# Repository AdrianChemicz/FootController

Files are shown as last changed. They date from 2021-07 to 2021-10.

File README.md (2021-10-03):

# FootController

## 1.Introduction

Main idea behind Footcontroller project was create device which allow user send keyboard event via foot move. This type of press key can be used in game in some circumstances it can be convienient more then standard press key on typical keyboard. When hold one button is required and press other parallel is required then footcontroller is good solution.

Device overview

## 2.Mechanical description

Device is connected to pc via USB cable. On device side is used USB mini connector.<br />
Device detect foot move via laser sensor and appropriate place for sensor was selected. <br />
In housing was prepared holes for power led, USB serial led, laser sensor and for USB connector. On below schematic was presented all part of device with descriptions.<br />

Device view

Index | Part of device description
------------ | -------------
1 | Laser sensor
2 | Power ON green LED
3 | Debug port connector
4 | USB serial port LED indicator
5 | Mini USB B port

On below schematic was presented all parts used in device.

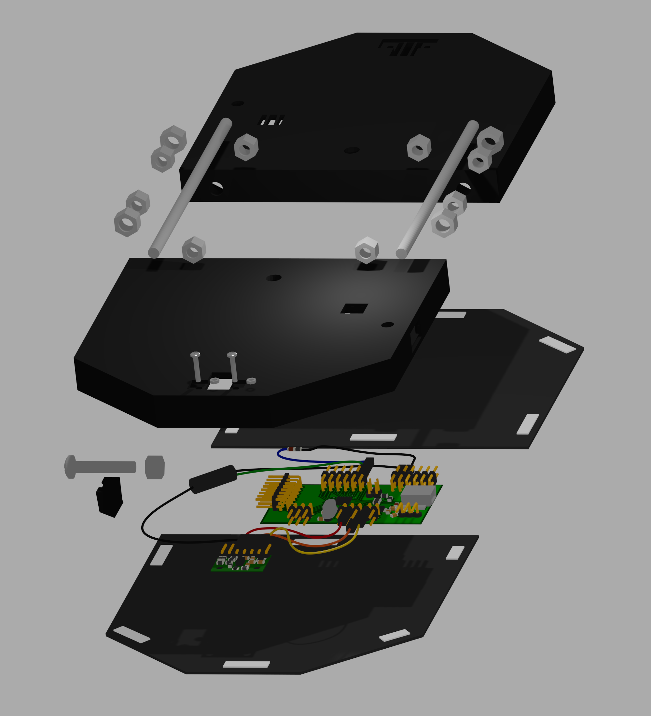
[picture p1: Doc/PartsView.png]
Device view


## 3.System usage

Device after connect to system is visible as composite device it mean that in single device can be present more than one function. In footcontroller was implemented HID keyboard and CDC(USB serial interface). HID keyboard functionality send event when laser event will be detected. Configuration which key must be presed, mode of pressing and threshold can be configure via USB serial interface.<br /><br />
USB serial interface driver of this device was added to this project and is available in folder "Driver".
When device is connected to PC and serial port will be open then key event will be suppres on 30s. On serial port device can display manual with supported command description. To display manual please send AT_HELP or HELP. Below was added help manual which will be send by device:
>Foot controller serial port is used to configure device and diagnose that device work properly<br />
>Configuration is performed using AT command. When serial port will be opened send button event will be blocked on 30s from serial port opening.<br />
>Device support below AT command<br />
>AT_SENSOR_ - command used to configure mode of laser sensor to decide how and when press keyboard button. Configuration of button is also possible.<br />
>Command expect parameters in order the same as order of described parameters.<br />
>1\. Sensor number - parameter describe about to which sensor number will be assigned key code, mode and threshold value. Value is stored in decimal format.<br />
>Format of parameter:<br />
>\<Sensor number\><br />
>2. Mode of pressing button - parameter decide how button will be pressed. Two options is possible:<br />
>PRESS - when event from laser sensor occur button will be pressed only one time even if event will be all time present.<br />
>HOLD - when event from laser sensor occur button will be pressed and will be present to moment when laser sensor detect that event disappear.<br />
>Format of parameter:<br />
>MODE_PRESS<br />
>3. Key code - parameter decide which key will be pressed when event occur. Value is stored in decimal format.<br />
>Format of parameter:<br />
>KEYCODE_6<br />
>Few key code example:<br />
>17 - N<br />
>6 - C<br />
>20 - Q<br />
>4. Threshold - parameter describe distance how far foot must be move from laser sensor to occur event. Distance is stored in milimiters and in decimal formats.<br />
>Format of parameter:<br />
>THRESHOLD_20<br />
>Example complete AT command formats:<br />
>AT_SENSOR_0_MODE_PRESS_KEYCODE_6_THRESHOLD_20<br />
>AT_SENSOR_0_MODE_HOLD_KEYCODE_17_THRESHOLD_20<br />
>AT_GET_RANGE_COUNT_ - command used to check range measured by laser sensor. Data displayed by this command is as raw milimeter without any preprocesing.<br />
>Command need only one parameter which mean number of get range samples. Number of samples must be set in decimal format.<br />
>Example complete AT command formats:<br />
>AT_GET_RANGE_COUNT_99<br />
>AT_STATUS - command used to verify that device work correctly.<br />
>Command return information about device current status, number of errors last errors code.<br />
>Status and error code equal 0 mean no errors<br />
>Example complete AT command format:<br />
>AT_STATUS<br />
>AT_EVENT_SUSPEND - command used to block button event send by device. This command is active to moment when serial port will be closed.<br />
>Example complete AT command format:<br />
>AT_EVENT_SUSPEND<br />
>AT_EVENT_PARAMETERS - command used to display parameters used by sensors. Command will display important information like:<br />
>key mode, key code, threshold need for cause key event, offset value(value used to compare with threshold is - offset value + raw laser sensor range)<br />

## 4.Electrical schematic

In device was used PCB with microcontroller LPC11U24. This PCB was created in KiCad application and all files created during board preparation was added to PCB project folder.
Below was added connection between main microcontroller and other part of system. In device was used pololu module with ST VL53L0X laser sensor(dev code of board: irs11a). Laser sensor is reset via BC817-25W NPN transistor.

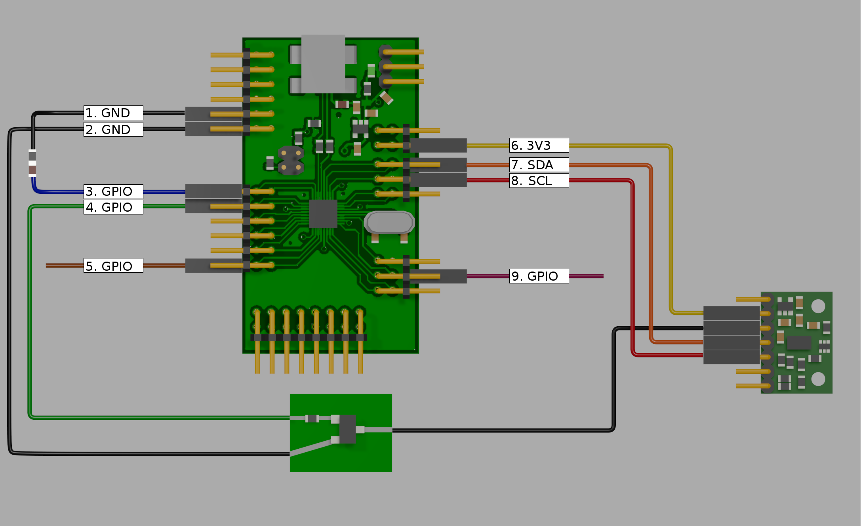
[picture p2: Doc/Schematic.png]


Index | Pin function | Pin usage
------------ | ------------ | -------------
1 | GND | Ground for LED
2 | GND | Ground connected to BC817-25W transistor emiter pin
3 | GPIO | Output port use to control CDC LED indicator
4 | GPIO | Output port use to control BC817-25W transistor base pin
5 | GPIO | Output port use to debug durring development process
6 | 3V3 | 3.3V power supply for laser sensor
7 | SDA | I2C data pin use to comunication with laser sensor
8 | SCL | I2C clock pin use to comunication with laser sensor
9 | GPIO | Input port use to block send key event from laser. Connect to ground to block event.

## 5.Housing of device

Housing of device was prepared in Blender application. Complete housing consist of two element main element and electronic board holder. To mount complete device is require put three or two nuts for screw and threaded rod to nut holes in main element. 

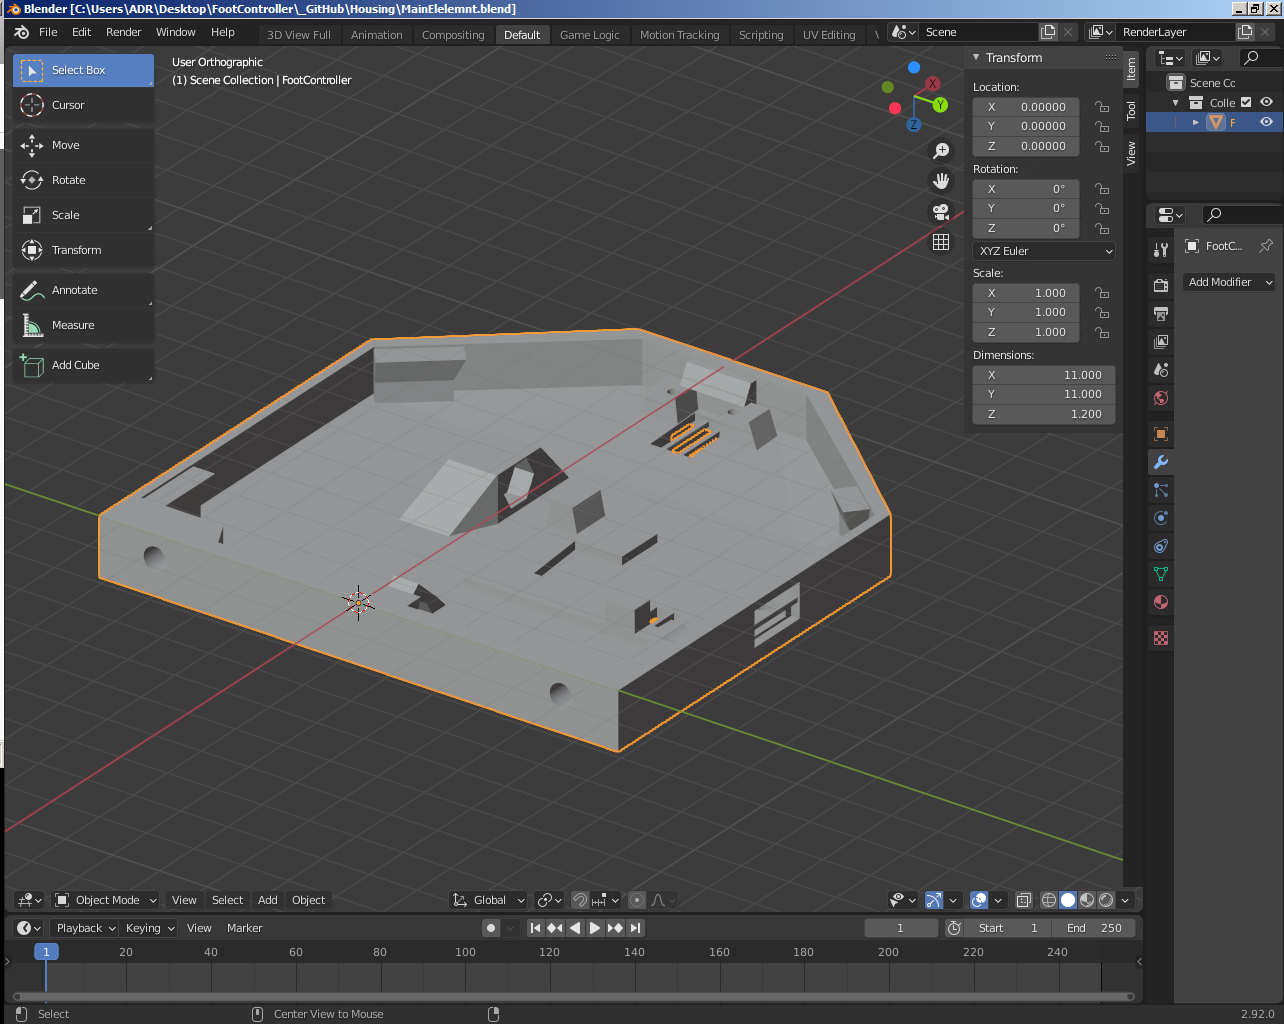
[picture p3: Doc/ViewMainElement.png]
Main element in blender


In Housing project folder was added blender files with single element and all steps(before using boolean modifier) necessary to create final element.

## 6.Code design

Footcontroller source code firmware was divided into few modules which was divided according to purpose. In below table was added all modules in project:

Module name | Module description
------------ | ------------
Descriptors.h | Contain USB things like structures and information which will be visible on PC after device connection
EEPROM_Driver.h | Provide function to read and write functions to store information about sensor activation parameters
FootController.h | Main module with main function. Module handle USB communication like serial and HID interfaces.
GPIO_Driver.h | Provide API for GPIO microcontrollers ports
HW_Driver.h | Module responsible for clock microcontroller clock settings and communication with laser sensor.
I2C_Driver.h | Provide API for I2C microcontroller interface
iap.h | Provide API to manage EEPROM memory and flash.
StringGenerateParseModule.h | Provide API to parse or generate strings. Functions in module are used by USB serial communication.

FootController.h module between other modules share FootControllerStructure which is visible as global variable. Many functions from other modules access to field in this structure directly.

To build firmware also was used ST VL53L0X API library to handle VL53L0X full sensor i2c comunication. ST library provide all necessary API to comunicate with sensor without manual call I2C API. API is available on below location:<br />
https://www.st.com/en/embedded-software/stsw-img005.html <br />
Project also use two other library which not exist in project directory but to correct compile file must be added outside. Those library are lpc_chip_11uxx_lib and nxp_lpcxpresso_11u14_usblib_device. 

Project to compile without errors require from user additional steps. Assign VID and PID number in Descriptors.c file because author of project isn't usb.org member or didn't buy VID number. The same thing must be performed with FootControllerSerialDriver.inf driver file in Driver project folder. Below was added screenshot both file with marked code lines when changes must be performed. In both file VID and PID must be the same.

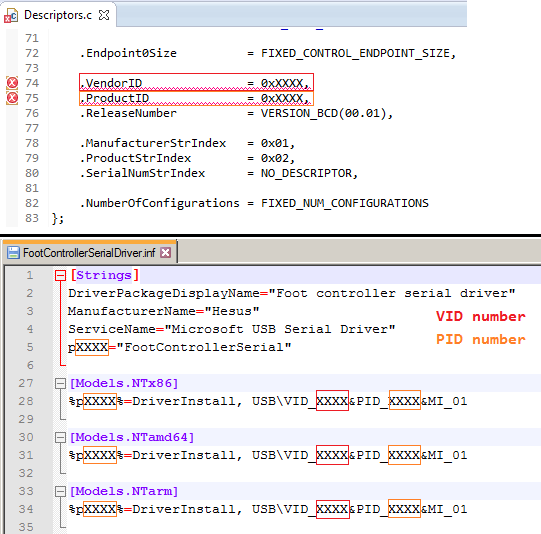
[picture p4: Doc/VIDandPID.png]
VID and PID


## 7.Execution sequence diagram

On below schematic was presented how application running on footcontroller to provide overal information before deeper code analisis.

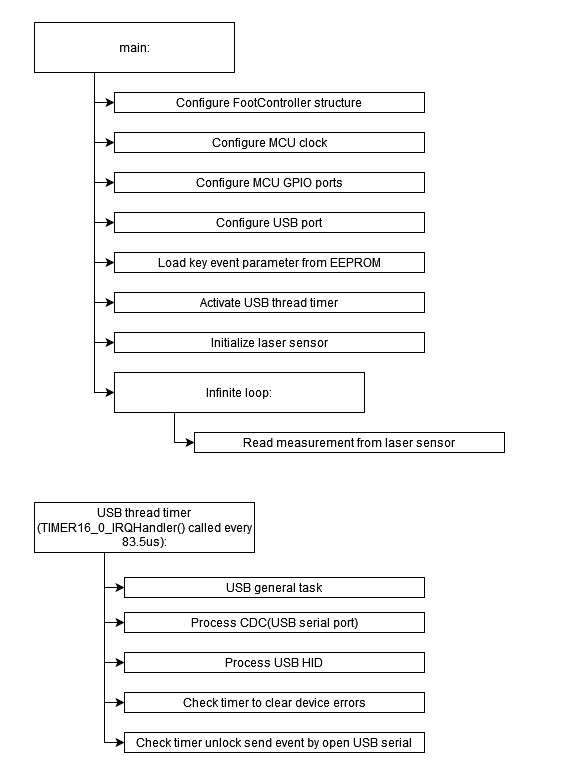
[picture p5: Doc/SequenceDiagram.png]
Sequence diagram

  
In main function after initialization is executed in infinite loop laser sensor handling. USB process is performed in TIMER16_0_IRQHandler timer interrupt which is call every 83.5 us.

## 8.Known issues

-Very often device send null signs in string to PC on serial port. Issue can be cause by incorrect use NXP USB library.

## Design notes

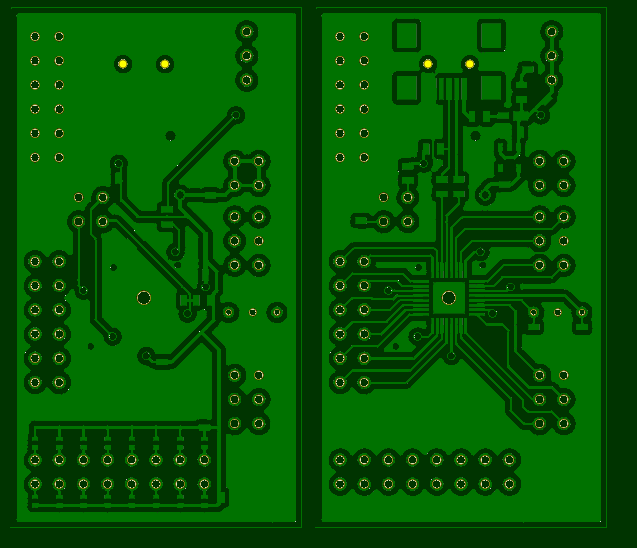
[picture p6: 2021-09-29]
Doc/Blender/PCB_Blender3.png

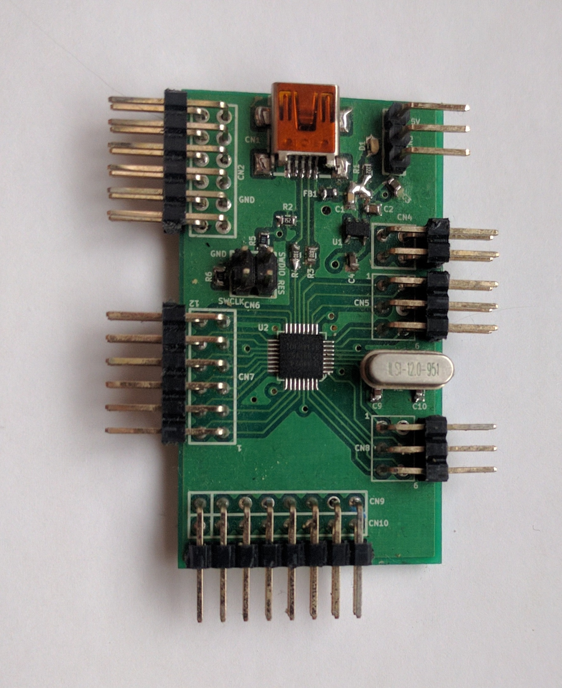
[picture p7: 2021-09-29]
PCB/PCB_UpLayer.jpg

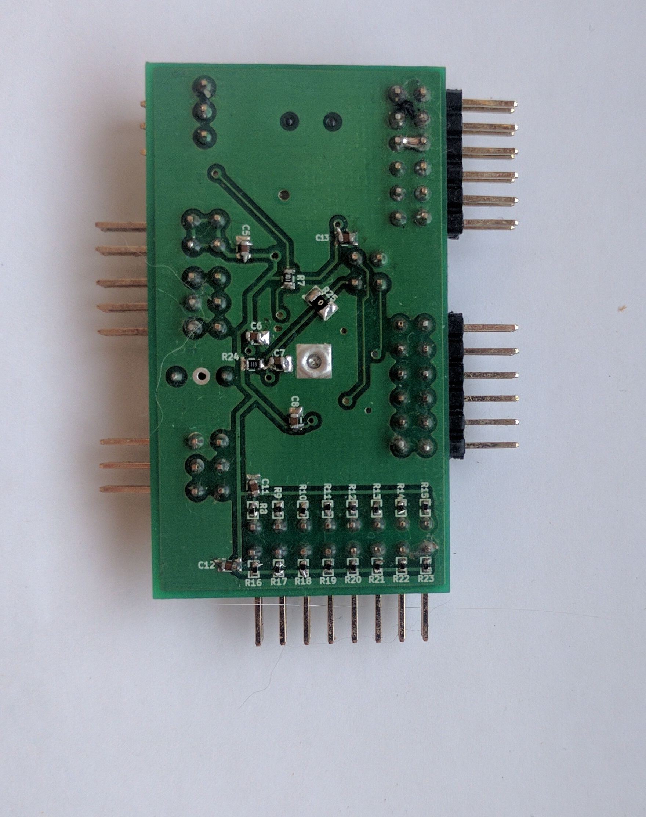
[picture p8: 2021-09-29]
PCB/PCB_DownLayer.jpg

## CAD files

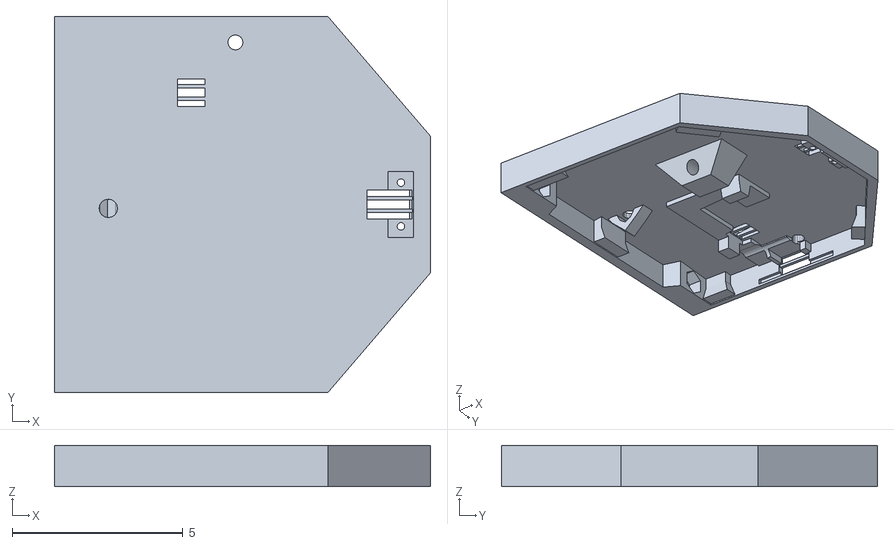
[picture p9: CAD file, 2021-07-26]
Housing/MainElelemnt.stl
11.0 x 11.0 x 1.20

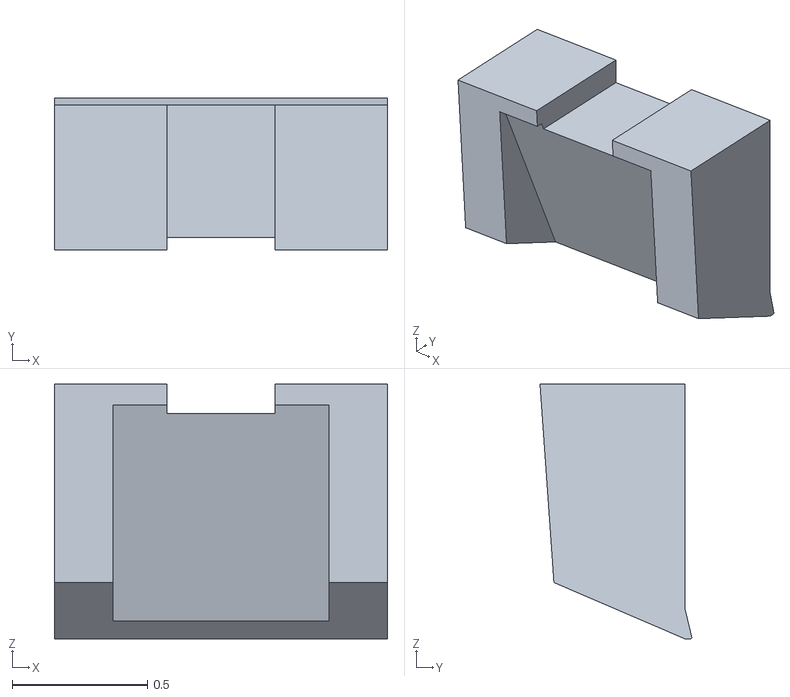
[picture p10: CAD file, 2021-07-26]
Housing/BoardLocker.stl
1.23 x 0.562 x 0.942

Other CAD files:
Doc/Blender/AllElementsFinal.blend
Doc/Blender/PartsView.blend
Doc/Blender/schematic.blend
Housing/BoardLocker.blend
Housing/BoardLocker_AllSteps.blend
Housing/MainElelemnt.blend
Housing/MainElelemnt_AllSteps.blend

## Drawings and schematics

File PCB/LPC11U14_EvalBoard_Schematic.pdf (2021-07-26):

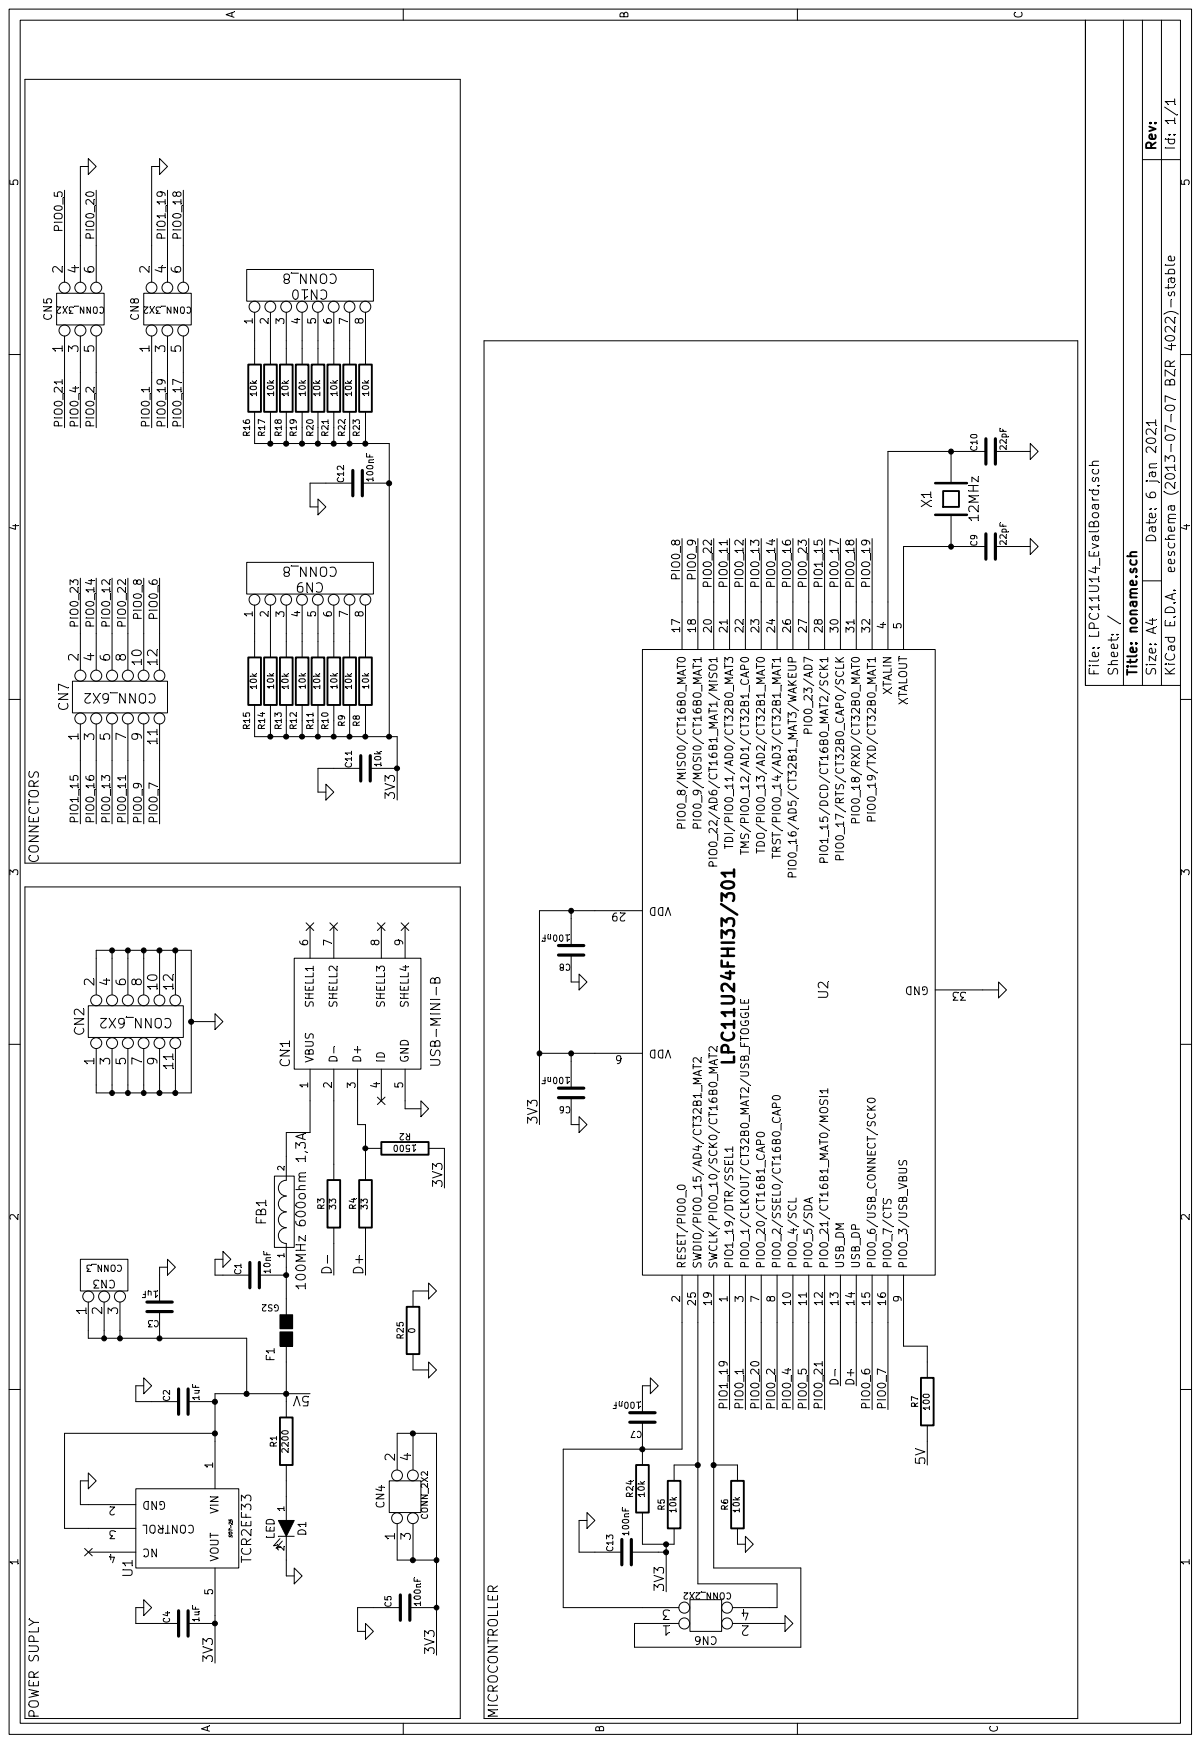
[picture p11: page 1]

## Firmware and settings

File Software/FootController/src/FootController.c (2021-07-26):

/*
 * Copyright (c) 2021, Adrian Chemicz
 * All rights reserved.
 *
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
 * THIS SOFTWARE IS PROVIDED BY THE COPYRIGHT HOLDERS AND CONTRIBUTORS "AS IS" AND
 * ANY EXPRESS OR IMPLIED WARRANTIES, INCLUDING, BUT NOT LIMITED TO, THE IMPLIED
 * WARRANTIES OF MERCHANTABILITY AND FITNESS FOR A PARTICULAR PURPOSE ARE
 * DISCLAIMED. IN NO EVENT SHALL COPYRIGHT HOLDER BE LIABLE FOR ANY
 * DIRECT, INDIRECT, INCIDENTAL, SPECIAL, EXEMPLARY, OR CONSEQUENTIAL DAMAGES
 * (INCLUDING, BUT NOT LIMITED TO, PROCUREMENT OF SUBSTITUTE GOODS OR SERVICES;
 * LOSS OF USE, DATA, OR PROFITS; OR BUSINESS INTERRUPTION) HOWEVER CAUSED AND
 * ON ANY THEORY OF LIABILITY, WHETHER IN CONTRACT, STRICT LIABILITY, OR TORT
 * (INCLUDING NEGLIGENCE OR OTHERWISE) ARISING IN ANY WAY OUT OF THE USE OF THIS
 * SOFTWARE, EVEN IF ADVISED OF THE POSSIBILITY OF SUCH DAMAGE.
 */

#include "USB.h"
#include <stdbool.h>
#include <string.h>
#include "Descriptors.h"
#include "chip.h"
#include "GPIO_Driver.h"
#include "vl53l0x_api.h"
#include "vl53l0x_platform.h"

#include "FootController.h"
#include "EEPROM_Driver.h"
#include "HW_Driver.h"
#include "StringGenerateParseModule.h"

/*****************************************************************************
*	String used by virtual serial USB in at command as responses
*****************************************************************************/
const char *helpString = "\r\nFoot controller serial port is used to configure device and diagnose that device work properly\r\n\
Configuration is performed using AT command. When serial port will be opened send button event will be blocked on 30s from serial port opening.\r\n\
Device support below AT command.\r\n\r\n\
AT_SENSOR_ - command used to configure mode of laser sensor to decide how and when press keyboard button. Configuration of button is also possible.\r\n\
Command expect parameters in order the same as order of described parameters.\r\n\r\n\
1. Sensor number - parameter describe about to which sensor number will be assigned key code, mode and threshold value. Value is stored in decimal format.\r\n\r\n\
Format of parameter:\r\n\
<Sensor number>\r\n\r\n\
2. Mode of pressing button - parameter decide how button will be pressed. Two options is possible:\r\n\
PRESS - when event from laser sensor occur button will be pressed only one time even if event will be all time present.\r\n\
HOLD - when event from laser sensor occur button will be pressed and will be present to moment when laser sensor detect that event disappear.\r\n\
Format of parameter:\r\n\
MODE_PRESS\r\n\r\n\
3. Key code - parameter decide which key will be pressed when event occur. Value is stored in decimal format.\r\n\
Format of parameter:\r\n\
KEYCODE_6\r\n\r\n\
Few key code example:\r\n\
17 - N\r\n\
6 - C\r\n\
20 - Q\r\n\r\n\
4. Threshold - parameter describe distance how far foot must be move from laser sensor to occur event. Distance is stored in milimiters and in decimal formats.\r\n\r\n\
Format of parameter:\r\n\
THRESHOLD_20\r\n\r\n\
Example complete AT command formats:\r\n\
AT_SENSOR_0_MODE_PRESS_KEYCODE_6_THRESHOLD_20\r\n\
AT_SENSOR_0_MODE_HOLD_KEYCODE_17_THRESHOLD_20\r\n\r\n\
AT_GET_RANGE_COUNT_ - command used to check range measured by laser sensor. Data displayed by this command is as raw milimeter without any preprocesing.\r\n\
Command need only one parameter which mean number of get range samples. Number of samples must be set in decimal format.\r\n\r\n\
Example complete AT command formats:\r\n\
AT_GET_RANGE_COUNT_99\r\n\r\n\
AT_STATUS - command used to verify that device work correctly.\r\n\
Command return information about device current status, number of errors last errors code.\r\n\
Status and error code equal 0 mean no errors\r\n\r\n\
Example complete AT command format:\r\n\
AT_STATUS\r\n\r\n\
AT_EVENT_SUSPEND - command used to block button event send by device. This command is active to moment when serial port will be closed.\r\n\
Example complete AT command format:\r\n\
AT_EVENT_SUSPEND\r\n\r\n\
AT_EVENT_PARAMETERS - command used to display parameters used by sensors. Command will display important information like:\r\n\
key mode, key code, threshold need for cause key event, offset value(value used to compare with threshold is - offset value + raw laser sensor range)\r\n";

const char *invalidParametersString = " - invalid parameters\r\n";
const char *correctParametersString = " - correct parameters\r\n";
const char *invalidCommandString = " - invalid command\r\n";
const char *errorProgramExecutionString = " - error in code execution\r\n";

/*****************************************************************************
*	Data for virtual serial port to control method of responses for at
*	commmand.
*****************************************************************************/
uint8_t receiveTransmitCdcBuffer[CDC_TXRX_EPSIZE];
uint8_t stringCdcTransmitBuffer[CDC_TXRX_EPSIZE*4];
CDC_MessageStructureType CDC_MessageStructure;

//global structure available in many modules. It is provided by FootController.h file
FootControllerStructureType FootControllerStructure;

static uint8_t PrevKeyboardHIDReportBuffer[sizeof(USB_KeyboardReport_Data_t)];

/*****************************************************************************
*	Structures used by NXP USB library. Structure is pass as reference for
*	NXP USB library functions. In below code was presenets structure for
*	HID and CDC interfaces.
*****************************************************************************/
//this structure is availiable externaly - is provided by FootController.h file
USB_ClassInfo_HID_Device_t Keyboard_HID_Interface = {
	.Config = {
		.InterfaceNumber              = 0,

		.ReportINEndpointNumber       = KEYBOARD_EPNUM,
		.ReportINEndpointSize         = KEYBOARD_EPSIZE,
		.ReportINEndpointDoubleBank   = false,

		.PrevReportINBuffer           = PrevKeyboardHIDReportBuffer,
		.PrevReportINBufferSize       = sizeof(PrevKeyboardHIDReportBuffer),
		.PortNumber             = 0,
	},
};

USB_ClassInfo_CDC_Device_t VirtualSerial_CDC_Interface = {
	.Config = {
		.ControlInterfaceNumber         = 1,

		.DataINEndpointNumber           = CDC_TX_EPNUM,
		.DataINEndpointSize             = CDC_TXRX_EPSIZE,
		.DataINEndpointDoubleBank       = false,

		.DataOUTEndpointNumber          = CDC_RX_EPNUM,
		.DataOUTEndpointSize            = CDC_TXRX_EPSIZE,
		.DataOUTEndpointDoubleBank      = false,

		.NotificationEndpointNumber     = CDC_NOTIFICATION_EPNUM,
		.NotificationEndpointSize       = CDC_NOTIFICATION_EPSIZE,
		.NotificationEndpointDoubleBank = false,
		.PortNumber             = 0,
	},
};

/*****************************************************************************************
* ProcessCdc() - main task of this function is process virtual serial USB request send by
* PC. In this part of code request is checked that it is handle by device and parameters
* added to request is correct. Request send to device use at command format. After
* validation request function also start appropriate process of command. Function set field
* in FootControllerStructure and later those data is used in other functions to generate
* data for response or decide how device will work. State how execution should be performed
* is stored in structure which is pass to function via structure pointer set as parameter.
*
* Parameters:
* @CDC_MessageStructurePointer: pointer to structure which contain parameters with state
* of processed command
*****************************************************************************************/
static void ProcessCdc(CDC_MessageStructureType *CDC_MessageStructurePointer)
{
	uint16_t recvByteCountTmp = CDC_Device_BytesReceived(&VirtualSerial_CDC_Interface);

	if (recvByteCountTmp > 0)
	{
		FootControllerStructure.processedCommand = (uint8_t)UNKNOWN_COMMAND;
		FootControllerStructure.correctCommandParametersFlag = true;

		CDC_MessageStructurePointer->duringSendTransactionFlag = false;
		CDC_MessageStructurePointer->transactionSendWaitCounter = NUMBER_OF_SEND_WAIT_CYCLE;

		memset(receiveTransmitCdcBuffer , 0, CDC_TXRX_EPSIZE);
		for (int i = 0; i < recvByteCountTmp; i++)
		{
			receiveTransmitCdcBuffer[i] = CDC_Device_ReceiveByte(&VirtualSerial_CDC_Interface);
		}

		//check that payload contain one of below strings on beginning
		//verify HELP COMMAND
		{
			if ((strstr(receiveTransmitCdcBuffer, "AT_HELP") != NULL && strstr(receiveTransmitCdcBuffer, "AT_HELP") == receiveTransmitCdcBuffer && receiveTransmitCdcBuffer[sizeof("AT_HELP")] == 0)
				|| (strstr(receiveTransmitCdcBuffer, "HELP") != NULL && strstr(receiveTransmitCdcBuffer, "HELP") == receiveTransmitCdcBuffer && receiveTransmitCdcBuffer[sizeof("HELP")] == 0))
			{
				FootControllerStructure.processedCommand = (uint8_t)HELP_COMAMND;
			}
		}
		//verify AT_STATUS
		{
			if (strstr(receiveTransmitCdcBuffer, "AT_STATUS") != NULL && strstr(receiveTransmitCdcBuffer, "AT_STATUS") == receiveTransmitCdcBuffer && receiveTransmitCdcBuffer[sizeof("AT_STATUS")] == 0)
			{
				FootControllerStructure.processedCommand = (uint8_t)STATUS_COMAMND;
			}
		}
		//verify AT_SENSOR_
		{
			if (strstr(receiveTransmitCdcBuffer, "AT_SENSOR_") != NULL && strstr(receiveTransmitCdcBuffer, "AT_SENSOR_") == receiveTransmitCdcBuffer)
			{
				SensorActivationParametersType sensorActivationParametersTmp;
				uint8_t sensorNumber;
				uint8_t copyOfCheckedBuffer[CDC_TXRX_EPSIZE];

				memcpy(copyOfCheckedBuffer, receiveTransmitCdcBuffer, CDC_TXRX_EPSIZE);

				FootControllerStructure.processedCommand = (uint8_t)CONFIGURE_SENSOR_COMAMND;

				if (parseConfigureSensorCommandParameters(strtok(&copyOfCheckedBuffer[sizeof("AT_SENSOR_") - 1], "_"), &sensorActivationParametersTmp, &sensorNumber))
				{
					if (sensorNumber > (MAX_SUPPORTED_SENSOR - 1))
					{
						FootControllerStructure.correctCommandParametersFlag = false;
					}
					else
					{
						FootControllerStructure.sensorActivationParametersTable[sensorNumber] = sensorActivationParametersTmp;

						SensorActivationParametersEepromStoreType sensorActivationParametersEepromContent;

						sensorActivationParametersEepromContent.sensorActivationParameters = sensorActivationParametersTmp;

						WriteSensorDataToEeprom(&sensorActivationParametersEepromContent, sensorNumber);
					}
				}
				else
				{
					FootControllerStructure.correctCommandParametersFlag = false;
				}
			}/* if (strstr(receiveTransmitCdcBuffer, "AT_SENSOR_") != NULL && strstr(receiveTransmitCdcBuffer, "AT_SENSOR_") == receiveTransmitCdcBuffer) */
		}
		//verify AT_GET_RANGE_COUNT_
		{
			if (strstr(receiveTransmitCdcBuffer, "AT_GET_RANGE_COUNT_") != NULL
				&& strstr(receiveTransmitCdcBuffer, "AT_GET_RANGE_COUNT_") == receiveTransmitCdcBuffer)
			{
				uint16_t numberOfRangeMeasurementTmp = 0;

				FootControllerStructure.processedCommand = (uint8_t)GET_RANGE_COMAMND;

				//verfy parameter
				numberOfRangeMeasurementTmp = atoi(&receiveTransmitCdcBuffer[sizeof("AT_GET_RANGE_COUNT_") - 1]);

				if(!onlyDigitsExistInString(&receiveTransmitCdcBuffer[sizeof("AT_GET_RANGE_COUNT_") - 1]))
				{
					FootControllerStructure.correctCommandParametersFlag = false;
				}

				if(numberOfRangeMeasurementTmp == 0 || numberOfRangeMeasurementTmp > MAX_SUPPORTED_LASER_MEASUREMENT)
				{
					FootControllerStructure.correctCommandParametersFlag = false;
				}

				FootControllerStructure.numberOfRangeMeasurement = numberOfRangeMeasurementTmp;

				FootControllerStructure.laserMeasurementIndex = 0;
				FootControllerStructure.laserMeasurementCurrentStoreIndex = 0;
				FootControllerStructure.laserMeasurementCurrentSendIndex = 0;
			}/* if (strstr(receiveTransmitCdcBuffer, "AT_GET_RANGE_COUNT_") != NULL
					&& strstr(receiveTransmitCdcBuffer, "AT_GET_RANGE_COUNT_") == receiveTransmitCdcBuffer) */
		}
		//verify AT_EVENT_SUSPEND
		{
			if (strstr(receiveTransmitCdcBuffer, "AT_EVENT_SUSPEND") != NULL && strstr(receiveTransmitCdcBuffer, "AT_EVENT_SUSPEND") == receiveTransmitCdcBuffer && receiveTransmitCdcBuffer[sizeof("AT_EVENT_SUSPEND")] == 0)
			{
				FootControllerStructure.processedCommand = (uint8_t)SUSPEND_EVENT_COMMAND;
			}
		}
		//verify AT_EVENT_PARAMETERS
		{
			if (strstr(receiveTransmitCdcBuffer, "AT_EVENT_PARAMETERS") != NULL && strstr(receiveTransmitCdcBuffer, "AT_EVENT_PARAMETERS") == receiveTransmitCdcBuffer && receiveTransmitCdcBuffer[sizeof("AT_EVENT_PARAMETERS")] == 0)
			{
				FootControllerStructure.processedCommand = (uint8_t)EVENT_PARAMETERS_COMMAND;
			}
		}

		CDC_MessageStructurePointer->duringSendTransactionFlag = true;
		CDC_MessageStructurePointer->stringOffset = 0;

		if (FootControllerStructure.correctCommandParametersFlag)
		{
			FootControllerStructure.stringFunctionGenerator = NULL;

			switch (FootControllerStructure.processedCommand)
			{
			case HELP_COMAMND:
				CDC_MessageStructurePointer->stringPointer = helpString;
				break;

			case STATUS_COMAMND:
				memset(stringCdcTransmitBuffer, 0, sizeof(stringCdcTransmitBuffer));
				CDC_MessageStructurePointer->stringPointer = stringCdcTransmitBuffer;
				generateStatusString(CDC_MessageStructurePointer->stringPointer);
				break;

			case CONFIGURE_SENSOR_COMAMND:
				CDC_MessageStructurePointer->stringPointer = correctParametersString;
				break;

			case GET_RANGE_COMAMND:
				memset(stringCdcTransmitBuffer, 0, sizeof(stringCdcTransmitBuffer));
				CDC_MessageStructurePointer->stringPointer = stringCdcTransmitBuffer;
				FootControllerStructure.stringFunctionGenerator = atGetRangeCountStringGenerator;
				break;

			case SUSPEND_EVENT_COMMAND:
				CDC_MessageStructurePointer->stringPointer = correctParametersString;
				FootControllerStructure.suspendSendEventByCdc = true;
				FootControllerStructure.suspendSerialCommandCounter = 0;
				FootControllerStructure.suspendSendEventPermanentlyWitOpenSerial = true;
				break;

			case EVENT_PARAMETERS_COMMAND:
				memset(stringCdcTransmitBuffer, 0, sizeof(stringCdcTransmitBuffer));
				CDC_MessageStructurePointer->stringPointer = stringCdcTransmitBuffer;
				generateEventParametersString(CDC_MessageStructurePointer->stringPointer);
				break;

			case UNKNOWN_COMMAND:
				CDC_MessageStructurePointer->stringPointer = invalidCommandString;
				break;

			default:
				CDC_MessageStructurePointer->stringPointer = errorProgramExecutionString;
				break;

			}/* switch (FootControllerStructure.processedCommand) */
		}
		else
		{
			CDC_MessageStructurePointer->stringPointer = invalidParametersString;
		}
	}/* if (recvByteCountTmp > 0) */

	if (CDC_MessageStructurePointer->duringSendTransactionFlag)
	{
		if (CDC_MessageStructurePointer->transactionSendWaitCounter >= NUMBER_OF_SEND_WAIT_CYCLE)
		{
			uint16_t bufferOffsetTmp = 0;
			uint16_t numberOfFreeBytesInBufferTmp = 0;
			uint16_t partOfStringLength = 0;

			if (CDC_MessageStructurePointer->stringOffset == 0)
			{
				bufferOffsetTmp = recvByteCountTmp;
			}

			numberOfFreeBytesInBufferTmp = CDC_TXRX_EPSIZE - bufferOffsetTmp;
			partOfStringLength = strlen(&CDC_MessageStructurePointer->stringPointer[CDC_MessageStructurePointer->stringOffset]);

			//case when last part of string is send
			if (numberOfFreeBytesInBufferTmp > partOfStringLength)
			{
				if ((numberOfFreeBytesInBufferTmp != CDC_TXRX_EPSIZE) || (partOfStringLength > 0))
				{
					memcpy(&receiveTransmitCdcBuffer[bufferOffsetTmp], &CDC_MessageStructurePointer->stringPointer[CDC_MessageStructurePointer->stringOffset], partOfStringLength);
					CDC_Device_SendData(&VirtualSerial_CDC_Interface, receiveTransmitCdcBuffer, bufferOffsetTmp + partOfStringLength);
				}

				CDC_MessageStructurePointer->stringOffset = 0;
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
}/* int main(void) */

/*****************************************************************************************
* EVENT_USB_Device_Connect() - called by NXP USB library more information is in library
* header file.
*****************************************************************************************/
void EVENT_USB_Device_Connect(void)
{

}

/*****************************************************************************************
* EVENT_USB_Device_Disconnect() - called by NXP USB library more information is in library
* header file.
*****************************************************************************************/
void EVENT_USB_Device_Disconnect(void)
{

}

/*****************************************************************************************
* EVENT_USB_Device_ConfigurationChanged() - called by NXP USB library. Configure endpoints
* for HID device, virtual serial port and enable start of frame events(events triggered
* by SOF frame on USB port send cyclically by HOST).
*****************************************************************************************/
void EVENT_USB_Device_ConfigurationChanged(void)
{
	bool ConfigSuccess = true;

	ConfigSuccess &= HID_Device_ConfigureEndpoints(&Keyboard_HID_Interface);
	ConfigSuccess &= CDC_Device_ConfigureEndpoints(&VirtualSerial_CDC_Interface);

	USB_Device_EnableSOFEvents();
}

/*****************************************************************************************
* EVENT_USB_Device_ControlRequest() - called by NXP USB library more information is in
* library header file.
*****************************************************************************************/
void EVENT_USB_Device_ControlRequest(void)
{
	HID_Device_ProcessControlRequest(&Keyboard_HID_Interface);
	CDC_Device_ProcessControlRequest(&VirtualSerial_CDC_Interface);
}

/*****************************************************************************************
* EVENT_USB_Device_Disconnect() - called by NXP USB library when start of frame occur on
* bus.
*****************************************************************************************/
void EVENT_USB_Device_StartOfFrame(void)
{
	HID_Device_MillisecondElapsed(&Keyboard_HID_Interface);
}

/*****************************************************************************************
* CALLBACK_HID_Device_CreateHIDReport() - called by NXP USB library more information is in
* library header file. In this function is created HID report for host with information
* that keyboard button was pressed.
*****************************************************************************************/
bool CALLBACK_HID_Device_CreateHIDReport(USB_ClassInfo_HID_Device_t *const HIDInterfaceInfo, uint8_t *const ReportID,
										 const uint8_t ReportType, void *ReportData, uint16_t *const ReportSize)
{
	USB_KeyboardReport_Data_t *KeyboardReport = (USB_KeyboardReport_Data_t *) ReportData;

	for (int i = 0, keyPressedNumbers = 0; i < MAX_SUPPORTED_SENSOR; i++)
	{
		if ((FootControllerStructure.laserSensorEventTable[i].thresholdState == false)
			&& FootControllerStructure.laserSensorEventTable[i].eventKeyWasSend
			&& FootControllerStructure.laserSensorEventTable[i].eventKeyState)
		{
			FootControllerStructure.laserSensorEventTable[i].eventKeyState = false;
		}

		if((GPIO_GetState(BLOCK_SEND_EVENT_PORT, BLOCK_SEND_EVENT_PIN) == true)
			&& (FootControllerStructure.laserSensorEventTable[i].eventKeyState == true)
			&& (FootControllerStructure.suspendSendEventByCdc == false))
		{
			KeyboardReport->KeyCode[keyPressedNumbers++] = FootControllerStructure.sensorActivationParametersTable[i].keyCode;
			FootControllerStructure.laserSensorEventTable[i].eventKeyWasSend = true;
		}
	}

	*ReportSize = sizeof(USB_KeyboardReport_Data_t);

	return true;
}

/*****************************************************************************************
* CALLBACK_HID_Device_ProcessHIDReport() - called by NXP USB library more information is
* in library header file.
*****************************************************************************************/
void CALLBACK_HID_Device_ProcessHIDReport(USB_ClassInfo_HID_Device_t *const HIDInterfaceInfo,
										  const uint8_t ReportID,
										  const uint8_t ReportType,
										  const void *ReportData,
										  const uint16_t ReportSize)
{

}

/*****************************************************************************************
* EVENT_CDC_Device_LineEncodingChanged() - called by NXP USB library more information is
* in library header file.
*****************************************************************************************/
void EVENT_CDC_Device_LineEncodingChanged(USB_ClassInfo_CDC_Device_t *const CDCInterfaceInfo)
{

}

/*****************************************************************************************
* EVENT_CDC_Device_ControLineStateChanged() - called by NXP USB library more information is
* in library header file. Function indicate when virtual serial port was opened or closed.
* This event is used to indicate on red LED that serial port is open or close. Call this
* event amd indication that port was opened cause suppres on 30s HID key event.
*****************************************************************************************/
void EVENT_CDC_Device_ControLineStateChanged(USB_ClassInfo_CDC_Device_t* const CDCInterfaceInfo)
{
	//port was opened
	if (CDCInterfaceInfo->State.ControlLineStates.HostToDevice & CDC_CONTROL_LINE_OUT_DTR)
	{
		GPIO_SetState(CDC_STATE_INDICATOR_PORT, CDC_STATE_INDICATOR_PIN, true);
		FootControllerStructure.suspendSendEventByCdc = true;
	}
	else//port was closed
	{
		GPIO_SetState(CDC_STATE_INDICATOR_PORT, CDC_STATE_INDICATOR_PIN, false);

		FootControllerStructure.suspendSendEventByCdc = false;
	}

	FootControllerStructure.suspendSerialCommandCounter = 0;
	FootControllerStructure.suspendSendEventPermanentlyWitOpenSerial = false;
}

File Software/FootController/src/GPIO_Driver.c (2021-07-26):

#include "GPIO_Driver.h"

#ifdef __LPC11XX__

static uint32_t* GPIO_GetBaseAddress(uint8_t portNumber)
{
	uint32_t* basePointer = 0;

	switch(portNumber)
	{
	case 0:
		basePointer = (uint32_t*)LPC_GPIO0;
		break;
	case 1:
		basePointer = (uint32_t*)LPC_GPIO1;
		break;
	case 2:
		basePointer = (uint32_t*)LPC_GPIO2;
		break;
	case 3:
		basePointer = (uint32_t*)LPC_GPIO3;
		break;
	default:
		basePointer = 0;
		break;
	}

	return basePointer;
}

#endif

void GPIO_Init(void)
{
	//configure pin PIO0_3/USB_VBUS to work as USB_VBUS
	Chip_IOCON_PinMuxSet(LPC_IOCON, 0,  3, (IOCON_FUNC1 | IOCON_MODE_INACT));
}

void GPIO_Direction(uint8_t port, uint8_t pin, GPIO_DIRECTION dir)
{
#ifdef __LPC11XX__
	uint32_t tmpDir = LPC_GPIO0->DIR;
	uint32_t dirMask = ~(1<<pin);
	LPC_GPIO_TypeDef *GPIO_Port = (LPC_GPIO_TypeDef*)GPIO_GetBaseAddress(port);

	GPIO_Port->DIR = (tmpDir & dirMask)|(dir<<pin);
#endif

#if defined(__LPC11UXX__) || defined(__LPC11E6X__)
	uint32_t tmpDir = LPC_GPIO->DIR[port];
	uint32_t dirMask = ~(1<<pin);

	LPC_GPIO->DIR[port] = (tmpDir & dirMask)|(dir<<pin);
#endif
}

void GPIO_SetState(uint8_t port, uint8_t pin, bool state)
{
#ifdef __LPC11XX__
	LPC_GPIO_TypeDef *GPIO_Port = (LPC_GPIO_TypeDef*)GPIO_GetBaseAddress(port);
	GPIO_Port->MASKED_ACCESS[1<<pin] = (state<<pin);
#endif

#if defined(__LPC11UXX__) || defined(__LPC11E6X__)
	LPC_GPIO->B[port][pin] = state;
#endif
}

bool GPIO_GetState(uint8_t port, uint8_t pin)
{	
#ifdef __LPC11XX__
	LPC_GPIO_TypeDef *GPIO_Port = (LPC_GPIO_TypeDef*)GPIO_GetBaseAddress(port);
	return ((GPIO_Port->MASKED_ACCESS[1<<pin])>>pin);
#endif

#if defined(__LPC11UXX__) || defined(__LPC11E6X__)
	return LPC_GPIO->B[port][pin];
#endif
}

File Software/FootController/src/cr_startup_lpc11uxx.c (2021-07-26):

//*****************************************************************************
// LPC11Uxx Microcontroller Startup code for use with LPCXpresso IDE
//
// Version : 140113
//*****************************************************************************
//
// Copyright(C) NXP Semiconductors, 2013-2014
// All rights reserved.
//
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
// Permission to use, copy, modify, and distribute this software and its
// documentation is hereby granted, under NXP Semiconductors' and its
// licensor's relevant copyrights in the software, without fee, provided that it
// is used in conjunction with NXP Semiconductors microcontrollers.  This
// copyright, permission, and disclaimer notice must appear in all copies of
// this code.
//*****************************************************************************

#if defined (__cplusplus)
#ifdef __REDLIB__
#error Redlib does not support C++
#else
//*****************************************************************************
//
// The entry point for the C++ library startup
//
//*****************************************************************************
extern "C" {
    extern void __libc_init_array(void);
}
#endif
#endif

#define WEAK __attribute__ ((weak))
#define ALIAS(f) __attribute__ ((weak, alias (#f)))

//*****************************************************************************
#if defined (__cplusplus)
extern "C" {
#endif

//*****************************************************************************
#if defined (__USE_CMSIS) || defined (__USE_LPCOPEN)
// Declaration of external SystemInit function
extern void SystemInit(void);
#endif

// Patch the AEABI integer divide functions to use MCU's romdivide library
#ifdef __USE_ROMDIVIDE
// Location in memory that holds the address of the ROM Driver table
#define PTR_ROM_DRIVER_TABLE ((unsigned int *)(0x1FFF1FF8))
// Variables to store addresses of idiv and udiv functions within MCU ROM
unsigned int *pDivRom_idiv;
unsigned int *pDivRom_uidiv;
#endif

//*****************************************************************************
//
// Forward declaration of the default handlers. These are aliased.
// When the application defines a handler (with the same name), this will 
// automatically take precedence over these weak definitions
//
//*****************************************************************************
     void ResetISR(void);
WEAK void NMI_Handler(void);
WEAK void HardFault_Handler(void);
WEAK void SVC_Handler(void);
WEAK void PendSV_Handler(void);
WEAK void SysTick_Handler(void);
WEAK void IntDefaultHandler(void);
//*****************************************************************************
//
// Forward declaration of the specific IRQ handlers. These are aliased
// to the IntDefaultHandler, which is a 'forever' loop. When the application
// defines a handler (with the same name), this will automatically take
// precedence over these weak definitions
//
//*****************************************************************************
void FLEX_INT0_IRQHandler (void) ALIAS(IntDefaultHandler);
void FLEX_INT1_IRQHandler (void) ALIAS(IntDefaultHandler);
void FLEX_INT2_IRQHandler (void) ALIAS(IntDefaultHandler);
void FLEX_INT3_IRQHandler (void) ALIAS(IntDefaultHandler);
void FLEX_INT4_IRQHandler (void) ALIAS(IntDefaultHandler);
void FLEX_INT5_IRQHandler (void) ALIAS(IntDefaultHandler);
void FLEX_INT6_IRQHandler (void) ALIAS(IntDefaultHandler);
void FLEX_INT7_IRQHandler (void) ALIAS(IntDefaultHandler);
void GINT0_IRQHandler (void) ALIAS(IntDefaultHandler);
void GINT1_IRQHandler (void) ALIAS(IntDefaultHandler);
void SSP1_IRQHandler (void) ALIAS(IntDefaultHandler);
void I2C_IRQHandler (void) ALIAS(IntDefaultHandler);
void TIMER16_0_IRQHandler (void) ALIAS(IntDefaultHandler);
void TIMER16_1_IRQHandler (void) ALIAS(IntDefaultHandler);
void TIMER32_0_IRQHandler (void) ALIAS(IntDefaultHandler);
void TIMER32_1_IRQHandler (void) ALIAS(IntDefaultHandler);
void SSP0_IRQHandler (void) ALIAS(IntDefaultHandler);
void UART_IRQHandler (void) ALIAS(IntDefaultHandler);
void USB_IRQHandler (void) ALIAS(IntDefaultHandler);
void USB_FIQHandler (void) ALIAS(IntDefaultHandler);
void ADC_IRQHandler (void) ALIAS(IntDefaultHandler);
void WDT_IRQHandler (void) ALIAS(IntDefaultHandler);
void BOD_IRQHandler (void) ALIAS(IntDefaultHandler);
void FMC_IRQHandler (void) ALIAS(IntDefaultHandler);
void USBWakeup_IRQHandler (void) ALIAS(IntDefaultHandler);

//*****************************************************************************
// The entry point for the application.
// __main() is the entry point for redlib based applications
// main() is the entry point for newlib based applications
//*****************************************************************************
#if defined (__REDLIB__)
extern void __main(void);
#else
extern int main(void);
#endif
//*****************************************************************************
//
// External declaration for the pointer to the stack top from the Linker Script
//
//*****************************************************************************
extern void _vStackTop(void);
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

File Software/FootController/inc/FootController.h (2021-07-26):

/*
 * Copyright (c) 2021, Adrian Chemicz
 * All rights reserved.
 *
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
 * THIS SOFTWARE IS PROVIDED BY THE COPYRIGHT HOLDERS AND CONTRIBUTORS "AS IS" AND
 * ANY EXPRESS OR IMPLIED WARRANTIES, INCLUDING, BUT NOT LIMITED TO, THE IMPLIED
 * WARRANTIES OF MERCHANTABILITY AND FITNESS FOR A PARTICULAR PURPOSE ARE
 * DISCLAIMED. IN NO EVENT SHALL COPYRIGHT HOLDER BE LIABLE FOR ANY
 * DIRECT, INDIRECT, INCIDENTAL, SPECIAL, EXEMPLARY, OR CONSEQUENTIAL DAMAGES
 * (INCLUDING, BUT NOT LIMITED TO, PROCUREMENT OF SUBSTITUTE GOODS OR SERVICES;
 * LOSS OF USE, DATA, OR PROFITS; OR BUSINESS INTERRUPTION) HOWEVER CAUSED AND
 * ON ANY THEORY OF LIABILITY, WHETHER IN CONTRACT, STRICT LIABILITY, OR TORT
 * (INCLUDING NEGLIGENCE OR OTHERWISE) ARISING IN ANY WAY OUT OF THE USE OF THIS
 * SOFTWARE, EVEN IF ADVISED OF THE POSSIBILITY OF SUCH DAMAGE.
 */

#ifndef _FOOT_CONTROLLER_H_
#define _FOOT_CONTROLLER_H_

/*
 * This is master module with main function. This module is reponsible for call
 * hardware initialization, handle USB communication via virtual serial port and
 * HID interface and call laser module. This module provide for other module
 * global FootControllerStructure structure which contain most important information
 * about device.
 */

#include <stdbool.h>
#include <stdint.h>

#define MAX_SUPPORTED_SENSOR 					1
#define MAX_SUPPORTED_LASER_MEASUREMENT 		99
#define NUMBER_OF_SEND_WAIT_CYCLE 				2000
#define LASER_JITTER_VALUE 						5
#define LASER_JITTER_SUSPEND_STATE_VALUE 		8
#define NUMBER_OF_COUNT_TO_CLEAR_LASER_OFFSET 	5
#define MAX_MEASUREMENTS_IN_SINGLE_SEND			5
#define MAX_SUPPORTED_RANGE_IN_MM				300
#define MINIMAL_LASER_SENSOR_RANGE_VALUE		16

//HVQFN33-16  PIO0_7/CTS  CN7-11
#define CDC_STATE_INDICATOR_PORT				0
#define CDC_STATE_INDICATOR_PIN					7

//HVQFN33-17  PIO0_8/MISO0/CT16B0_MAT0  CN7-10
#define FIRST_SENSOR_CONTROL_LINE_PORT			0
#define FIRST_SENSOR_CONTROL_LINE_PIN			8

//HVQFN33-18  PIO0_9/MOSI0/CT16B0_MAT1  CN7-9
#define SECOND_SENSOR_CONTROL_LINE_PORT			0
#define SECOND_SENSOR_CONTROL_LINE_PIN			9

//HVQFN33-1  PIO1_19/DTR/SSEL1  CN8-4
#define BLOCK_SEND_EVENT_PORT					1
#define BLOCK_SEND_EVENT_PIN					19

//HVQFN33-27  PIO0_23/AD7  CN7-2
#define DEBUG_PORT								0
#define DEBUG_PIN								23

#define LASER_SENSOR_CONFIG_BEGINNING			64
#define LASER_MEASUREMENT_BUFFER_DEPH			10

#define NUMBER_OF_STORED_ERRORS					8
#define NUMBER_OF_CYCLE_TO_CLEAR_ERROR			40000
#define INITIALIZATION_ERROR_CODE				1
#define NO_FAULT_ERROR_CODE						0
#define ERROR_CODE_POSITION						0
#define INDEX_CODE_POSITION						1

#define NUMBER_OF_CYCLE_TO_REACH_1S_BY_TIMER	11976

typedef enum SELECTED_COMMAND_TYPE
{
	HELP_COMAMND,
	STATUS_COMAMND,
	CONFIGURE_SENSOR_COMAMND,
	GET_RANGE_COMAMND,
	SUSPEND_EVENT_COMMAND,
	EVENT_PARAMETERS_COMMAND,
	UNKNOWN_COMMAND
}SELECTED_COMMAND;

typedef enum KEY_MODE_TYPE
{
	PRESS_KEY,
	HOLD_KEY
}KEY_MODE;

typedef struct
{
	uint8_t keyCode;
	uint8_t keyMode;
	uint16_t laserRangeThreshold;
}SensorActivationParametersType;

typedef struct
{
	SensorActivationParametersType sensorActivationParameters;
	uint16_t counter;
	uint16_t checksum;
}SensorActivationParametersEepromStoreType;
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

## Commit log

2021-07-26 Added driver file for FootController device
2021-07-26 Added housing file
    In this commit I added two file with model for 3D printer and files for Blender which contain all steps which was prepare to create housing.
    [BoardLocker.blend, BoardLocker.stl, BoardLocker_AllSteps.blend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]
2021-07-26 Added PCB files
    In this commit was added file for PCB topics like gerber files, KiCad files with schematic and PCB and PDF file with schematic.
    [LPC11U14_EvalBoard.kicad_pcb, LPC11U14_EvalBoard.sch]
2021-07-26 Added Software files
    In this commit was added complite eclipse project with source code for FootController device.
2021-09-29 PCB photo
    PCB photo was added.
2021-09-29 Add blender file
    [AllElementsFinal.blend, PartsView.blend, schematic.blend]
2021-10-03 update driver file
    Not all PID numbers was deleted
